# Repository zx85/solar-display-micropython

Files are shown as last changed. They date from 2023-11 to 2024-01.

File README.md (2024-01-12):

# Solis Cloud API display for ESP32

A version of a Solis Cloud API solar display using MicroPython and a 1602 LCD screen, for the ESP32 board.

It uses the [Solis API](https://solis-service.solisinverters.com/en/support/solutions/articles/44002212561-api-access-soliscloud) which allows users of Solis inverters to collect current and historical data, and displays it on a handy little screen.

### Note: ESP32 only
This currently doesn't work on a WeMos D1mini (and maybe other ESP8266 devices) because of this:
[github.com/micropython/micropython-lib/issues/400](https://github.com/micropython/micropython-lib/issues/400) 

## Hardware
Here's what I used to make my version:
- Wemos LOLIN32 LITE (or off-brand equivalent ESP32)
- HD44780 based 1602 LCD screen
- PCF8574 based I2C interface
- 100Ω resistor
- 4 channel logic level shifter
- 5x 2kΩ resistor pull-ups
- a mini USB charging board (to get 5V from a micro USB connector)
- a 5V power supply
- a collection of miscellaneous push buttons

These are all (currently) available for a total of less than £10 from your favourite online electronics retailer.

I'm using a WEMOS LOLIN32 LITE which has just about enough memory and processing power to do the job. 

There's no reason why it can't work with another ESP32 device - a WEMOS S2MINI is smaller, for example. You'd need to adjust the pins to suit, obviously.

The LOLIN32 LITE has a handy battery input that goes into a voltage regulator rated at 6V, so I desoldered that and used it for the 5V input to the board.

The LCD display I'm using is a 1602 one based on the HD44780 controller, and an PCF8574 I2C interface.

I'm using a PWM-capable output pin to drive the backlight LED, so I used a logic level converter (since it needs 5V and the PWM output pin is only 3.3v) to drive it, and desoldered the on-board resistor. I think some of the I2C interfaces come with a jumper, so removing the resistor might not be required.

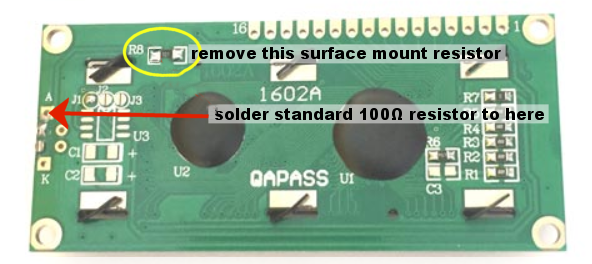
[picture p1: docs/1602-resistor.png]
resistor position


#### Pins used:
- 5 - LED PWM output
- 19 - I2C SCL
- 23 - I2C SDA
- 34 - LED brightness button
- 35 - Day summmary button
- 36 - Hard reset button
- EN - Soft reset button

### Circuit diagram
Here's my attempt at the circuit diagram - it looks a lot more complicated than it actually is, and Kicad doesn't have the symbol for a Lolin32 so it's only a close approximation (and a hot mess, if I'm honest).

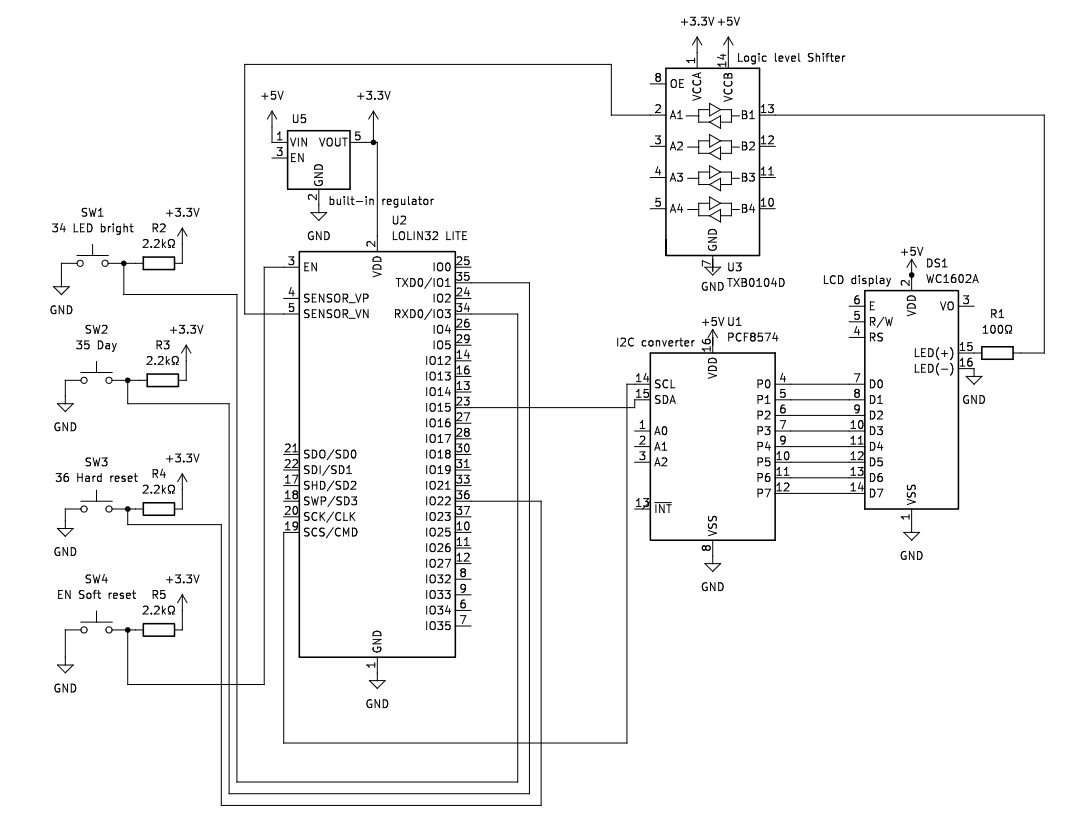
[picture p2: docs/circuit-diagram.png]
circuit diagram


All it really needs is a 5v power input, with three connections - one to the input of the ESP32, one to the level shifter and one to the LCD display. The rest is just data lines to the various push buttons and display inputs.

I included 2.2k resistors as pullups since the internal ones don't seem to work too well (having read up about it, they're closer to 10k and therefore a bit floaty).

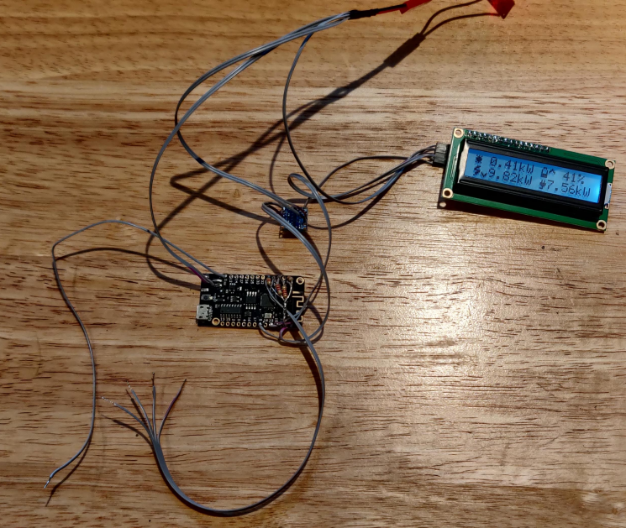
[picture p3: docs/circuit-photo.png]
circuit photo


## Software
To get this working you'll first need to install MicroPython on your device. The instructions at [docs.micropython.org](https://docs.micropython.org/en/latest/esp32/tutorial/intro.html) are clear and easy to follow.

I use Microsoft [Visual Studio Code](https://code.visualstudio.com/) with the [Pymakr-preview](https://marketplace.visualstudio.com/items?itemName=pycom.pymakr-preview) extension installed (**note:** it's the preview version that, at time of writing, actually works. For some reason the standard version doesn't!)

It should be fairly straightforward to copy the code to the device.

### Libraries used
I made use of the following excellent libraries - and I'm grateful to the developers for making my life so much easier!

- https://github.com/dhylands/python_lcd ([*homepage*](https://www.davehylands.com/))
- https://github.com/anson-vandoren/esp8266-captive-portal ([*blog post*](https://ansonvandoren.com/posts/esp8266-captive-web-portal-part-1/))

### Requirements
To use this, you'll need access to the soliscloud monitor API. This is well-documented on the [solis-inverters.com](https://solis-service.solisinverters.com/en/support/solutions/articles/44002212561-api-access-soliscloud) website.

Once you have access to the API, you'll need:
- Solis API Key - available from the [API management page](https://soliscloud.com/#/apiManage)
- Solis API Secret - as above
- The ID of your Solis inverter. This can be found by clicking on the [Device Overview](https://soliscloud.com/#/station/device) of the soliscloud website, and then clicking on the serial number of the inverter
- The Serial number of your Solis inverter. This is the number you clicked on above

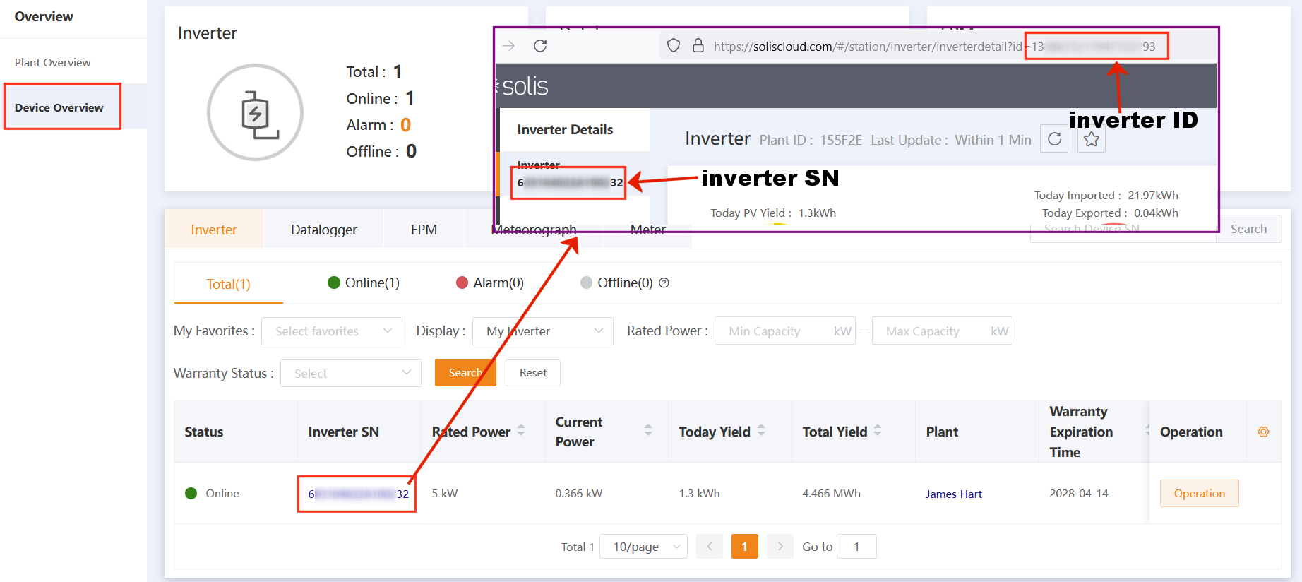
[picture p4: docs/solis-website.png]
Solis website example


### How it works

#### boot.py
The `boot.py` section generally deals with setting the credentials for the wifi network and Solis API. It loads a captive portal with an SSID starting `SolarDisplay-` and once you've connected to it with a handy device and web browser, you can enter the appropriate information there. Once it's done, it should reset and start displaying the data.

#### main.py
This runs a bunch of uasyncio loops, mainly to make web service calls to Solis every 45 seconds. While it's doing that, a dot appears around the middle of the bottom row of the screen. If it's successful, the dot disappears. If it's unsuccessful, it turns into two dots. 

The button on Pin 35 - if there is information available - prints the current daily solar generation, and the time of the last update by the datalogger (it only updates every five minutes). 

If there's been a problem with getting data, the last HTTP response code from solis cloud will be displayed, in order to help with diagnosis (for example, if the key/secret/id/serial combination are wrong, it'll return a 403).

The button on Pin 34 increases the brightness of the LED until it gets to maxium, then goes to 0

The button on Pin 36 is the hard reset button - hold it for 3 seconds and it clears the credentials and restarts at the captive portal.

Finally, the reset button does a normal reset on the ESP32, in case it's got stuck or something.

## 3D printed case

In the docs/Case design folder you can find 3MF and STL files for the case design. The PCBs are intended to click into the rear section, and the display clicks into the front.

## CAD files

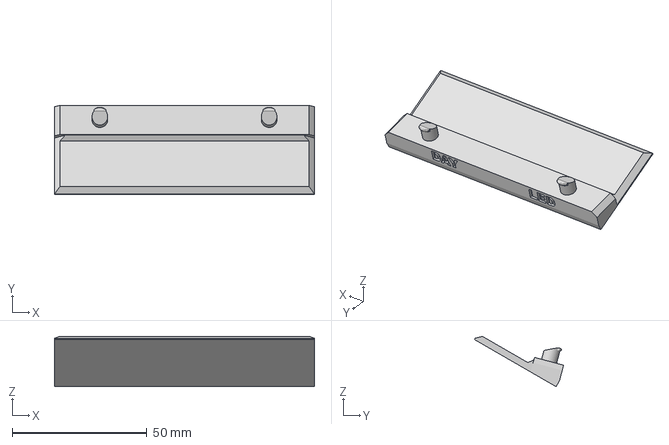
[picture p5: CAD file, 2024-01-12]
docs/Case design/Solar display - base.3mf
96.4 x 33.1 x 18.7 mm

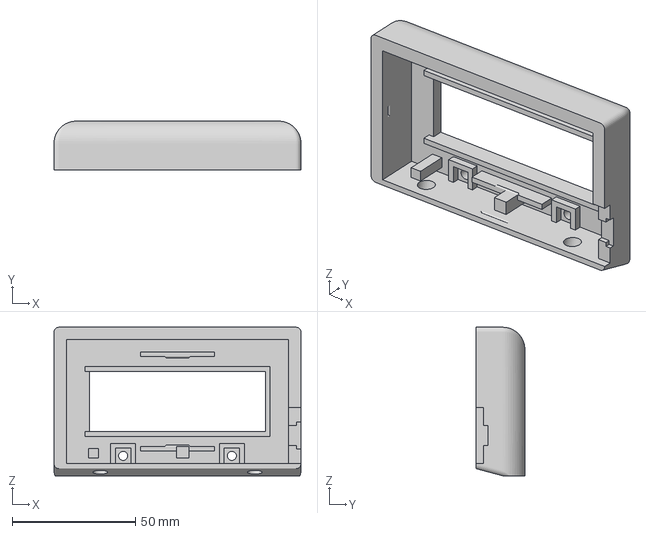
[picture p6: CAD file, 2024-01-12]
docs/Case design/Solar display - front.3mf
100.4 x 19.8 x 60.4 mm

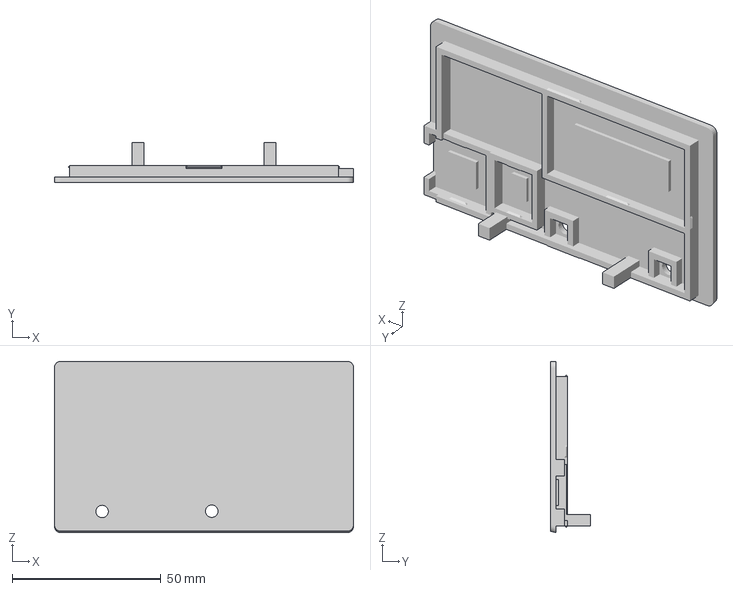
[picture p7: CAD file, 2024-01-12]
docs/Case design/Solar display - rear.3mf
100.4 x 13.5 x 57.5 mm

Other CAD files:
docs/Case design/STL/Solar display - base.stl
docs/Case design/STL/Solar display - front.stl
docs/Case design/STL/Solar display - rear.stl

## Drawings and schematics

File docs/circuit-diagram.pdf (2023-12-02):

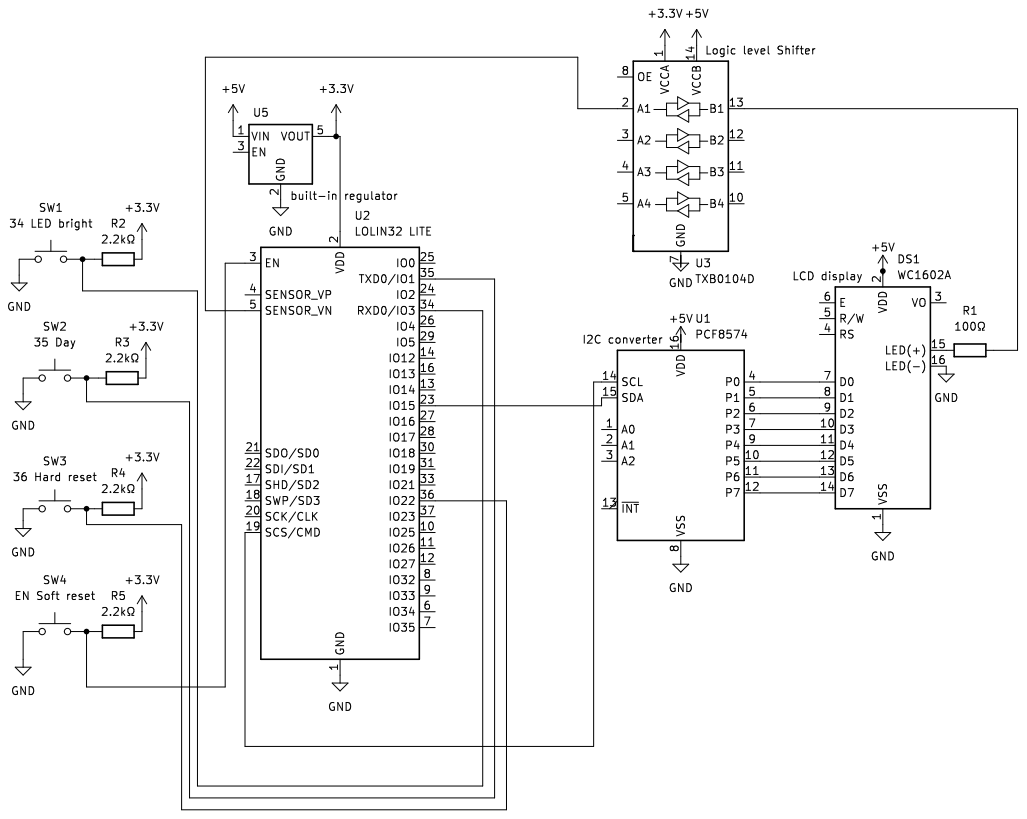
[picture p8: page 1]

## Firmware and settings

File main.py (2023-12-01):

# on-board goodies
import sys
import os
import gc
import uasyncio
from hashlib import sha1
import urequests as requests
from time import sleep, gmtime, localtime
import network
import ntptime
from machine import Pin, I2C, PWM, reset

sys.path.append("/include")
# external things
from machine_i2c_lcd import I2cLcd
import hmac
import base64
import md5

# Global variables so it can be persistent
solar_usage = {}
led_bright = 800
CRED_FILE = "config/credentials.env"
SOLIS_FILE = "config/solis.env"

# Device descriptors
# define the display
# WEMOS LOLIN32 ESP32 Lite pinout
sdaPIN = Pin(23)
sclPIN = Pin(19)
# S2MINI pinout (I think)
# sdaPIN = Pin(33)
# sclPIN = Pin(35)
i2c = I2C(0, sda=sdaPIN, scl=sclPIN, freq=400000)
devices = i2c.scan()
for device in devices:
    print("i2c address is" + hex(device))
I2C_ADDR = 0x27
I2C_NUM_ROWS = 2
I2C_NUM_COLS = 16
lcd = I2cLcd(i2c, I2C_ADDR, I2C_NUM_ROWS, I2C_NUM_COLS)
led_out = PWM(Pin(5), freq=500, duty=800)
# Usage: led_out.init(freq=500, duty=led_bright)
led_btn = Pin(34, Pin.IN, Pin.PULL_UP)
day_btn = Pin(35, Pin.IN, Pin.PULL_UP)
reset_btn = Pin(36, Pin.IN, Pin.PULL_UP)


# Local time doings
def stringTime(thisTime):
    year, month, date, hour, minute, second, week_day, year_day = thisTime
    week_day_lookup = b"MonTueWedThuFriSatSun"
    month_lookup = b"JanFebMarAprMayJunJulAugSepOctNovDec"
    stringTime = (
        week_day_lookup.decode()[week_day * 3 : week_day * 3 + 3]
        + ", "
        + f"{date:02}"
        + " "
        + month_lookup.decode()[(month - 1) * 3 : (month - 1) * 3 + 3]
        + " "
        + f"{year:02}"
        + " "
        + f"{hour:02}"
        + ":"
        + f"{minute:02}"
        + ":"
        + f"{second:02}"
        + " GMT"
    )
    return stringTime


def getSolis(solisInfo):
    solar_dict = {}
    url = solisInfo["solisUrl"]
    CanonicalizedResource = solisInfo["solisPath"]

    req = url + CanonicalizedResource
    VERB = "POST"
    Content_Type = "application/json"

    Date = stringTime(gmtime())

    Body = (
        '{"pageSize":100,  "id": "'
        + solisInfo["solisId"].decode()
        + '", "sn": "'
        + solisInfo["solisSn"].decode()
        + '" }'
    )
    Content_MD5 = base64.b64encode(md5.digest(Body.encode("utf-8"))).decode("utf-8")
    encryptStr = (
        VERB
        + "\n"
        + Content_MD5
        + "\n"
        + Content_Type
        + "\n"
        + Date
        + "\n"
        + CanonicalizedResource
    )
    h = hmac.new(
        solisInfo["solisSecret"].decode().encode("utf-8"),
        msg=encryptStr.encode("utf-8"),
        digestmod=sha1,
    )
    Sign = base64.b64encode(h.digest())
    Authorization = "API " + solisInfo["solisKey"].decode() + ":" + Sign.decode("utf-8")

    header = {
        "Content-MD5": Content_MD5,
        "Content-Type": Content_Type,
        "Date": Date,
        "Authorization": Authorization,
    }
    solar_text = ""
    solar_resp = "!!!"
    try:
        gc.collect()
        gc.threshold(gc.mem_free() // 4 + gc.mem_alloc())
        print("\n\nPOST to " + url + "...", end="")
        resp = requests.post(req, data=Body, headers=header, timeout=60)
        print("[" + str(resp.status_code) + "]")
        solar_text = resp.text
        solar_resp = resp.status_code
    except Exception as e:
        print("get solar_usage didn't work sorry because this: " + str(e))

    solar_dict = {"resp": solar_resp}

    if solar_text != "":
        for each_field in solar_text.split(","):
            if '"dataTimestamp":' in each_field:
                solar_dict["timestamp"] = each_field.split(":")[1]
            if '"pac":' in each_field:
                solar_dict["solar_in"] = each_field.split(":")[1]
            if '"batteryCapacitySoc":' in each_field:
                solar_dict["battery_per"] = each_field.split(":")[1]
            if '"psum":' in each_field:
                solar_dict["grid_in"] = each_field.split(":")[1]
            if '"familyLoadPower":' in each_field:
                solar_dict["power_used"] = each_field.split(":")[1]
            if '"eToday":' in each_field:
                solar_dict["solar_today"] = each_field.split(":")[1]
    return solar_dict


def lcd_line(lcd, lcd_string, row=0, col=0):
    if row == 0 and col == 0:  # presume we want to clear the screen if it's top left
        lcd.clear()
    lcd.move_to(col, row)
    lcd.putstr(lcd_string)


# Coroutine: get the solis data every 45 seconds
def display_data(solar_usage, lcd, force=False):
    # do something funny with the battery icon ha
    battery_icon = bytearray([0x0E, 0x0E, 0x11, 0x1F, 0x1F, 0x1F, 0x1F, 0x1F])
    battery_int = int(float(solar_usage["battery_per"]))
    grid_float = float(solar_usage["grid_in"])
    # Sanity check printing business
    print("solis timestamp is: " + solar_usage["timestamp"])
    print("solar_in is: " + solar_usage["solar_in"])
    print("battery_per is: " + solar_usage["battery_per"])
    print("grid_in is: " + solar_usage["grid_in"])
    print("power_used is: " + solar_usage["power_used"])
    print("solar_today is: " + solar_usage["solar_today"] + "\n")
    if force or (solar_usage["timestamp"] != solar_usage["prev_timestamp"]):
        print("Solis data has been updated - do the LCD thing...")
        # LCD business
        if battery_int < 90:
            battery_icon[1] = 0x0A
        if battery_int < 75:
            battery_icon[2] = 0x11
        if battery_int < 60:
            battery_icon[3] = 0x11
        if battery_int < 45:
            battery_icon[4] = 0x11
        if battery_int < 30:
            battery_icon[5] = 0x11
        if battery_int < 15:
            battery_icon[6] = 0x11
        lcd.custom_char(5, battery_icon)
        lcd.clear()
        # Solar
        lcd.putstr(chr(0) + " " + solar_usage["solar_in"][:4] + "kW      ")
        # Battery
        lcd.move_to(9, 0)
        lcd.putstr(chr(5))
        if battery_int == solar_usage["prev_battery_int"]:
            lcd.putstr("=")
        if battery_int < solar_usage["prev_battery_int"]:
            lcd.putstr(chr(4))
        if battery_int > solar_usage["prev_battery_int"]:
            lcd.putstr(chr(3))
        lcd.putstr(" " + str(battery_int) + "%     ")
        # Grid
        lcd.move_to(0, 1)
        lcd.putstr(chr(1))
        if grid_float == 0:
            lcd.putstr("=0kW   ")
        if grid_float < 0:
            lcd.putstr(chr(4) + solar_usage["grid_in"][1:5] + "kW    ")
        if grid_float > 0:
            lcd.putstr(chr(3) + solar_usage["grid_in"][:4] + "kW    ")
        # Usage
        lcd.move_to(9, 1)
        lcd.putstr(
            chr(2)
            + solar_usage["power_used"][:4]
            + "kW"
            + " " * (4 - len(solar_usage["power_used"][:4]))
        )


async def timer_solis_data(solisInfo, lcd):
    global solar_usage
    solar_usage["prev_battery_int"] = 0
    solar_usage["prev_timestamp"] = "0"
    while True:
        lcd_line(lcd, chr(6), 1, 8)
        solar_dict = getSolis(solisInfo)
        if "timestamp" in solar_dict:
            lcd_line(lcd, " ", 1, 8)
            solar_usage.update(solar_dict)
            display_data(solar_usage, lcd)
            # ready to loop then
            solar_usage["prev_battery_int"] = int(float(solar_usage["battery_per"]))
            solar_usage["prev_timestamp"] = solar_usage["timestamp"]
        else:
            lcd_line(lcd, chr(7), 1, 8)
            print("No data returned")
            if "resp" in solar_dict:
                solar_usage["resp"] = solar_dict["resp"]
        await uasyncio.sleep(45)


async def wait_brightness():
    global led_bright
    while True:
        led_out.duty(led_bright)
        await uasyncio.sleep_ms(100)


# Coroutine: reset button
async def wait_reset_button():
    global CRED_FILE
    btn_count = 0
    btn_max = 75
    while True:
        if reset_btn.value() == 1:
            btn_count = 0
        if reset_btn.value() == 0:
            print(f"Pressed - count is {str(btn_count)}")
            btn_count = btn_count + 1
        if btn_count >= btn_max:
            lcd_line(lcd, "Full reset")
            sleep(2)
            os.remove(CRED_FILE)
            reset()
        await uasyncio.sleep(0.04)


# Coroutine: led button
async def wait_led_button():
    global led_bright
    prev_btn = 1
    while True:
        if led_btn.value() == 1 and prev_btn == 0:
            led_bright = (led_bright + 200) % 1200
        prev_btn = led_btn.value()
        await uasyncio.sleep(0.04)


# Coroutine: day button press
async def wait_day_button(day_btn):
    btn_prev = day_btn.value()
    while (day_btn.value() == 1) or (day_btn.value() == btn_prev):
        btn_prev = day_btn.value()
        await uasyncio.sleep(0.04)


# Corouteine: display solar today
async def display_solar_today(lcd):
    if "solar_today" in solar_usage:
        print("Solar today is " + solar_usage["solar_today"])
        print("Last updated: " + solar_usage["timestamp"])
        lcd_line(lcd, "Today: " + solar_usage["solar_today"][:4] + "kW")
        solis_time = stringTime(
            localtime(int(float(solar_usage["timestamp"].replace('"', "")) / 1000))
        )[-12:].replace("GMT", "UTC")
        lcd_line(lcd, "at " + solis_time, 1)
    else:
        if "resp" in solar_usage:
            print("No Solar today data - oops")
            print(f"last response code: {solar_usage['resp']}")
            lcd_line(lcd, "solis response:")
            lcd_line(lcd, str(solar_usage["resp"]), 1)
    await uasyncio.sleep(5)
    # put the old data back
    if "timestamp" in solar_usage:
        display_data(solar_usage, lcd, True)
    print("And I'm done.")


async def main():
    global led_bright
    led_out.init(freq=500, duty=led_bright)

    # Custom character bits
    solar_icon = bytearray([0x00, 0x15, 0x0E, 0x1F, 0x1F, 0x0E, 0x15, 0x00])
    lcd.custom_char(0, solar_icon)
    grid_icon = bytearray([0x07, 0x0E, 0x18, 0x1F, 0x07, 0x0E, 0x0C, 0x10])
    lcd.custom_char(1, grid_icon)
    mains_icon = bytearray([0x00, 0x0A, 0x0A, 0x1F, 0x1F, 0x0E, 0x04, 0x1C])
    lcd.custom_char(2, mains_icon)
    up_icon = bytearray([0x04, 0x0E, 0x1B, 0x11, 0x00, 0x00, 0x00, 0x00])
    lcd.custom_char(3, up_icon)
    down_icon = bytearray([0x00, 0x00, 0x00, 0x00, 0x11, 0x1B, 0x0E, 0x04])
    lcd.custom_char(4, down_icon)
    try_dot = bytearray([0x00, 0x00, 0x00, 0x00, 0x00, 0x00, 0x00, 0x04])
    lcd.custom_char(6, try_dot)
    bad_dot = bytearray([0x00, 0x00, 0x00, 0x00, 0x00, 0x00, 0x00, 0x0A])
    lcd.custom_char(7, bad_dot)

    solisInfo = {}
    # Now separate credentials
    global CRED_FILE
    global SOLIS_FILE

    try:
        with open(CRED_FILE, "rb") as f:
            contents = f.read().split(b",")
            if len(contents) == 6:
                (
                    solisInfo["wifiSSID"],
                    solisInfo["wifiPass"],
                    solisInfo["solisKey"],
                    solisInfo["solisSecret"],
                    solisInfo["solisId"],
                    solisInfo["solisSn"],
                ) = contents
    except OSError:
        print("No or invalid credentials file - please reset and start again")
        sys.exit()

    f = open("config/solis.env")
    for line in f:
        if "=" in line:
            thisAttr = line.strip().split("=")[0]
            thisVal = line.strip().split("=")[1]
            solisInfo[thisAttr] = thisVal
    f.close()

    # Initial display goodness
    lcd.clear()
    lcd.hide_cursor()
    lcd_line(lcd, "Solis data - SN:")
    lcd_line(lcd, solisInfo["solisSn"].decode(), 1)
    sleep(2)

    # Configure the network
    wlan = network.WLAN(network.STA_IF)
    wlan.active(True)
    print("Connecting", end="")
    lcd_line(lcd, "Connecting to")
    lcd_line(lcd, "WiFi ...", 1)
    wlan.connect(solisInfo["wifiSSID"], solisInfo["wifiPass"])
    ipAddress, netMask, defaultGateway, DNS = wlan.ifconfig()
    wifiCount = 0
    while ipAddress == "0.0.0.0" and wifiCount < 30:
        print(".", end="")
        sleep(1)
        ipAddress, netMask, defaultGateway, DNS = wlan.ifconfig()
        wifiCount += 1

    if ipAddress == "0.0.0.0":
        print("No WiFi connection - please check details in solis.env")
        sys.exit()

    print("Wifi connected - IP address is: " + ipAddress)
    lcd_line(lcd, "Connected. SSID:")
    lcd_line(lcd, solisInfo["wifiSSID"].decode(), 1)
    sleep(2)
    lcd_line(lcd, "Connected. IP:")
    lcd_line(lcd, ipAddress, 1)
    sleep(2)
    lcd_line(lcd, "Getting data ...")

    ntptime.host = "0.uk.pool.ntp.org"
    ntptime.settime()

    # Main loop
    # Get the solis data

    uasyncio.create_task(timer_solis_data(solisInfo, lcd))
    uasyncio.create_task(wait_brightness())
    uasyncio.create_task(wait_led_button())
    uasyncio.create_task(wait_reset_button())

    while True:
        await wait_day_button(day_btn)
        await display_solar_today(lcd)


if __name__ == "__main__":
    try:
        # Start event loop and run entry point coroutine
        uasyncio.run(main())
    except KeyboardInterrupt:
        pass

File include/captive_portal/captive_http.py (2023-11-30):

import uerrno
import uio
import uselect as select
import usocket as socket

from collections import namedtuple
from credentials import Creds

WriteConn = namedtuple("WriteConn", ["body", "buff", "buffmv", "write_range"])
ReqInfo = namedtuple("ReqInfo", ["type", "path", "params", "host"])

from server import Server

import gc


def unquote(string):
    """stripped down implementation of urllib.parse unquote_to_bytes"""

    if not string:
        return b""

    if isinstance(string, str):
        string = string.encode("utf-8")
    string = string.replace(b"+", b" ")

    # split into substrings on each escape character
    bits = string.split(b"%")
    if len(bits) == 1:
        return string  # there was no escape character

    res = [bits[0]]  # everything before the first escape character

    # for each escape character, get the next two digits and convert to
    for item in bits[1:]:
        code = item[:2]
        char = bytes([int(code, 16)])  # convert to utf-8-encoded byte
        res.append(char)  # append the converted character
        res.append(
            item[2:]
        )  # append anything else that occurred before the next escape character

    return b"".join(res)


class HTTPServer(Server):
    def __init__(self, poller, local_ip):
        super().__init__(poller, 80, socket.SOCK_STREAM, "HTTP Server")
        if type(local_ip) is bytes:
            self.local_ip = local_ip
        else:
            self.local_ip = local_ip.encode()
        self.request = dict()
        self.conns = dict()
        self.routes = {
            b"/": b"./include/captive_portal/index.html",
            b"/login": self.login,
        }

        self.ssid = None

        # queue up to 5 connection requests before refusing
        self.sock.listen(5)
        self.sock.setblocking(False)

    def set_ip(self, new_ip, new_ssid):
        """update settings after connected to local WiFi"""

        self.local_ip = new_ip.encode()
        self.ssid = new_ssid
        self.routes = {b"/": self.connected}

    @micropython.native
    def handle(self, sock, event, others):
        if sock is self.sock:
            # client connecting on port 80, so spawn off a new
            # socket to handle this connection
            print("- Accepting new HTTP connection")
            self.accept(sock)
        elif event & select.POLLIN:
            # socket has data to read in
            print("- Reading incoming HTTP data")
            self.read(sock)
        elif event & select.POLLOUT:
            # existing connection has space to send more data
            print("- Sending outgoing HTTP data")
            self.write_to(sock)

    def accept(self, server_sock):
        """accept a new client request socket and register it for polling"""

        try:
            client_sock, addr = server_sock.accept()
        except OSError as e:
            if e.args[0] == uerrno.EAGAIN:
                return

        client_sock.setblocking(False)
        client_sock.setsockopt(socket.SOL_SOCKET, socket.SO_REUSEADDR, 1)
        self.poller.register(client_sock, select.POLLIN)

    def parse_request(self, req):
        """parse a raw HTTP request to get items of interest"""

        req_lines = req.split(b"\r\n")
        req_type, full_path, http_ver = req_lines[0].split(b" ")
        path = full_path.split(b"?")
        base_path = path[0]
        query = path[1] if len(path) > 1 else None
        query_params = (
            {
                key: val
                for key, val in [param.split(b"=") for param in query.split(b"&")]
            }
            if query
            else {}
        )
        host = [line.split(b": ")[1] for line in req_lines if b"Host:" in line][0]

        return ReqInfo(req_type, base_path, query_params, host)

    def login(self, params):
        ssid = unquote(params.get(b"ssid", None))
        password = unquote(params.get(b"password", None))
        soliskey = unquote(params.get(b"soliskey", None))
        solissecret = unquote(params.get(b"solissecret", None))
        solisid = unquote(params.get(b"solisid", None))
        solissn = unquote(params.get(b"solissn", None))
        print(
            f"I got as far as the parameters - {ssid} {password} {soliskey} {solissecret} {solisid} {solissn}"
        )
        # Write out credentials
        Creds(
            ssid=ssid,
            password=password,
            soliskey=soliskey,
            solissecret=solissecret,
            solisid=solisid,
            solissn=solissn,
        ).write()

        headers = (
            b"HTTP/1.1 307 Temporary Redirect\r\n"
            b"Location: http://{:s}\r\n".format(self.local_ip)
        )

        return b"", headers

    def connected(self, params):
        headers = b"HTTP/1.1 200 OK\r\n"
        body = open("./connected.html", "rb").read() % (self.ssid, self.local_ip)
        return body, headers

    def get_response(self, req):
        """generate a response body and headers, given a route"""

        headers = b"HTTP/1.1 200 OK\r\n"
        route = self.routes.get(req.path, None)

        if type(route) is bytes:
            # expect a filename, so return contents of file
            print(f"route is {route}")
            return open(route, "rb"), headers

        if callable(route):
            # call a function, which may or may not return a response
            response = route(req.params)
            body = response[0] or b""
            headers = response[1] or headers
            return uio.BytesIO(body), headers

        headers = b"HTTP/1.1 404 Not Found\r\n"
        return uio.BytesIO(b""), headers

    def is_valid_req(self, req):
        if req.host != self.local_ip:
            # force a redirect to the MCU's IP address
            return False
        # redirect if we don't have a route for the requested path
        return req.path in self.routes

    def read(self, s):
        """read in client request from socket"""

        data = s.read()
        if not data:
            # no data in the TCP stream, so close the socket
            self.close(s)
            return

        # add new data to the full request
        sid = id(s)
        self.request[sid] = self.request.get(sid, b"") + data

        # check if additional data expected
        if data[-4:] != b"\r\n\r\n":
            # HTTP request is not finished if no blank line at the end
            # wait for next read event on this socket instead
            return

        # get the completed request
        req = self.parse_request(self.request.pop(sid))

        if not self.is_valid_req(req):
            headers = (
                b"HTTP/1.1 307 Temporary Redirect\r\n"
                b"Location: http://{:s}/\r\n".format(self.local_ip)
            )
            body = uio.BytesIO(b"")
            self.prepare_write(s, body, headers)
            return
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

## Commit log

2023-07-14 So so close - might have to upgrade to ESP32
2023-09-29 doing stuff with i2c
2023-12-01 button definitions
2023-12-01 All the buttons - good to go
2023-12-02 couple of tweaks
2023-12-05 tidied up the LED bit of the README
2024-01-12 3D objects
    [Solar display - base.stl, Solar display - base.3mf, Solar display - front.3mf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]
